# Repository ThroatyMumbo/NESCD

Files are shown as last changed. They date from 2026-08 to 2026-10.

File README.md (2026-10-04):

# NESCD-001

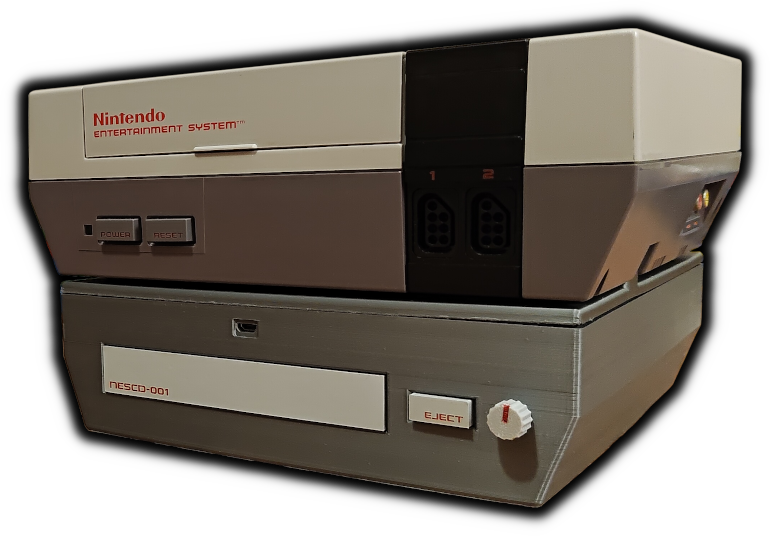
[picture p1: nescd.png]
NESCD-001


An unofficial homemade CD add-on for the NES, just because!

This repo contains the schematics, PCB, 3D printable STLs for the shell, sticker labels, and the firmware.

## How it works

It's basically an RP2350B hooked up to both an Everdrive N8 Pro and an IDE CD drive. It reads the game ROM off the CD, uploads it to the Everdrive over USB
and asks the menu to install it, then watches a mailbox byte in the cart's CHR RAM for the game to ask for music. The RP2350B is the coordinator in the
middle that bridges the NES/Everdrive and the CD drive.

Project video: https://www.youtube.com/watch?v=6D8RWVwW4ZI

## Hardware
- The main PCB (see [pcb/](pcb/))
- A standard 40-pin IDE CD drive
- Everdrive N8 Pro

## Build

```
cd firmware && ./flash.sh
```

## Making a disc

The demo game needs [cc65](https://cc65.github.io/) (`ca65`/`ld65`), plus
`python3` with `numpy`, `ffmpeg` for the audio, and `xorriso` to burn.

```
cd game && make         # demo.nes, four music tracks, and build/demo.img
cd game && make burn    # burn build/demo.img and read it back to check
```

To put your own game on a disc, pass [`mkgamedisc.py`](firmware/tools/mkgamedisc.py)
an iNES ROM and one track per music byte:

```
python3 firmware/tools/mktrack.py theme.wav -o theme.rom --loop-start 4.2
python3 firmware/tools/mkgamedisc.py -o mygame.img --title "MY GAME" --nes mygame.nes --track 1=theme.rom --verify
firmware/burn.sh mygame.img
```

## Using it

If everything goes right, you should be able to just put a burned disc into the CD drive while the NES is on and sitting on the Everdrive menu.
It'll auto-boot the game once it's read and uploaded to the Everdrive.

### Playing an audio CD

Arguably the most practical use for this thing: A CD player!

Insert the CD while on the Everdrive menu and it should automatically launch the player.

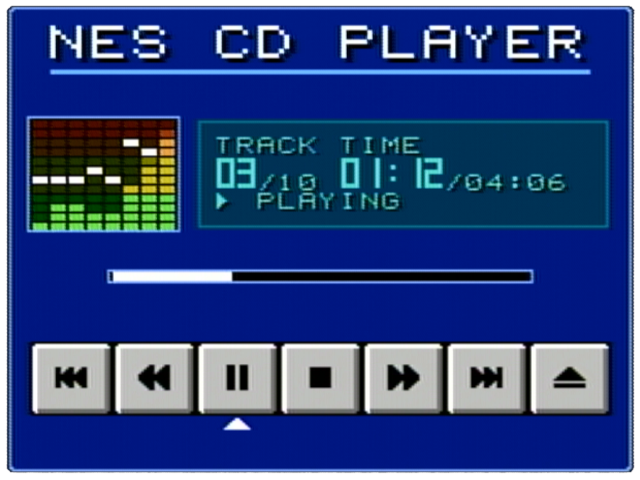
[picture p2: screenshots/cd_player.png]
Audio CD player


## FAQ

### What?
Great question! I came up with the idea for this project while reading about the canceled SNES CD-ROM add-on. I was originally going to make my own
version of that add-on, but decided it'd be funnier and weirder if I took it a step further and made one for NES.

### Why?
Because it's fun.

### Who?
It's me! Your old pal - Throaty Mumbo!

### Where are the FMVs you showed in the video?
I chose not to include any FMV-related code here because to get that working I had to semi-reverse engineer
Something Nerdy's [Bad Apple!! Ultimate NES Demake](https://somethingnerdy.com/downloads/), which is currently closed source.
The team has mentioned they're planning to formally open source their MXM mapper (which this demo presumably uses, actually not sure)
once their game *Former Dawn* is released. I didn't feel good about publishing reverse engineered code from an indie development team
for my stupid meme project, especially when they have plans to release it themselves.

### Why not stream audio from the Everdrive?
I originally wanted to do this, but was hitting a ceiling on the Everdrive USB bandwidth. I'd likely have to add some form of aggressive compression
to make room. It's also a nice touch to use the expansion port instead.

The USB cable poking out on the front is by far the biggest blemish on the design of this contraption, so I did look at moving everything to the
expansion port. Unfortunately the bandwidth there is even more limited than the USB route.

Plus, the expansion port audio allows more flexibility with mixing and volume control - hence the volume knob on the front.

### How is this thing powered?
A single molex cable from a wall adapter ([this one](https://www.amazon.com/Coolerguys-100-240v-Molex-Power-Adapter/dp/B000MGG6SC) in particular).
The 5V/12V rails are split between the CD drive and the board + the NES output. I took the end of a spare NES power cable and hooked it up to
a buck converter that converts the 12V input to ~9.5V so you can power the NES as well (the plug pokes out of the top of the box). That way
you only need one wall outlet to get the entire thing running. You can also power the NES separately from its regular adapter - the plug
coming out of the NESCD is optional.

### Couldn't you power everything off VRAW?
This was my initial plan, but it seemed tight considering the stock NES adapter (1.3A) has to power the NES, Everdrive, RP2350, DAC, and the CD drive.
The power adapter for that Fideco drive sled I tested with initially outputs at 2A, so I figured a dedicated 2A molex adapter (which supposedly outputs 2A on
5V and 12V each, at least according to the label) would be the minimum. But honestly I didn't actually test running the CD drive and everything else off
VRAW at the same time, so this was more of a cautious choice than based off of objective measurement. If it works it'd be a nice improvement for
an eventual v2 design.

### How do you get back to the Everdrive menu once you've inserted a disc?
This is still something I'm trying to figure out. AFAIK there's no way to trigger a soft reset on the NES. However one guaranteed solution is to
hook up the NES power output rail to a relay switch. That way if the board ever needs the NES to reset, it can just turn it on and off from the
source. Not super elegant but it should work.

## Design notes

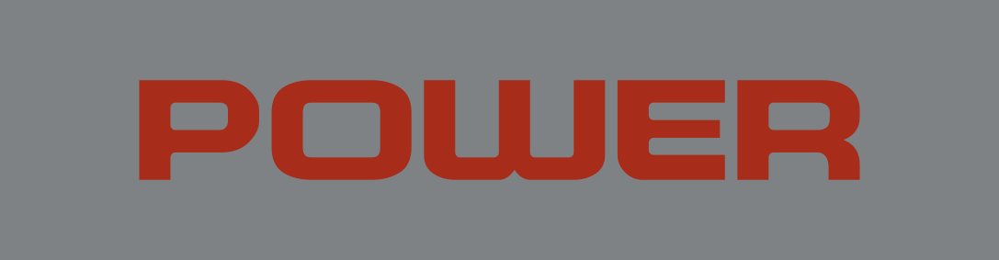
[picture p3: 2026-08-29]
labels/power_label.png

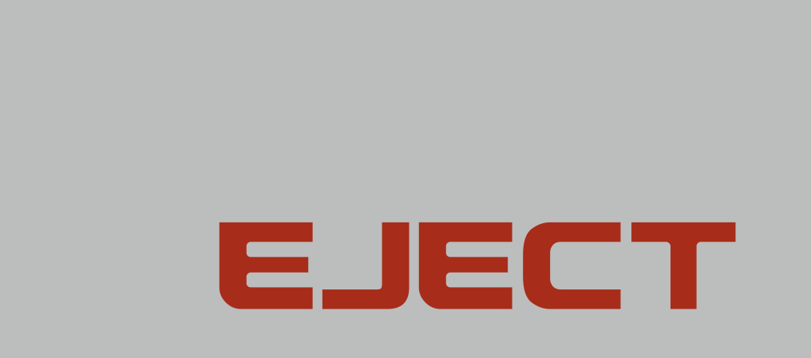
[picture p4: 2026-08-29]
labels/button_label.png

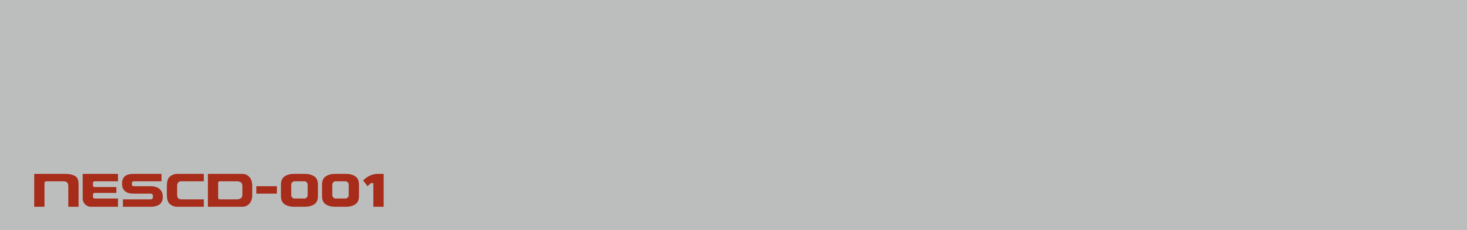
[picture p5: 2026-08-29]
labels/cd_label.png

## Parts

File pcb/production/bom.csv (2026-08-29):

Designator | Footprint | Quantity | Value | LCSC Part #
A1 | Pimoroni_PGA2350 | 1 | PGA2350
A2 | PCM5102A_Board | 1 | PCM5102A
C1 | CP_Radial_D6.3mm_P2.50mm | 1 | 100u/16V
C2, C3, C5, C6, C8 | C_Disc_D5.0mm_W2.5mm_P5.00mm | 5 | 100n
C4 | CP_Radial_D5.0mm_P2.50mm | 1 | 22u/10V
C7 | CP_Radial_D5.0mm_P2.50mm | 1 | 22u/16V
H1, H2, H3, H4 | MountingHole_3.2mm_M3_DIN965_Pad | 4 | M3
J1 | TE_MATE-N-LOK_350211-1_1x04_P5.08mm_Vertical | 1 | MOLEX IN
J2 | TE_MATE-N-LOK_350211-1_1x04_P5.08mm_Vertical | 1 | MOLEX TO DRIVE
J3 | TerminalBlock_Phoenix_MKDS-1,5-4-5.08_1x04_P5.08mm_Horizontal | 1 | PWR SWITCH
J4 | TerminalBlock_Phoenix_MKDS-1,5-2-5.08_1x02_P5.08mm_Horizontal | 1 | 12V TO BUCK
J5 | IDC-Header_2x20_P2.54mm_Vertical | 1 | IDE 40
J6 | USB_Micro_DIP_1x05_P2.54mm | 1 | USB TO EVERDRIVE
J7 | PinHeader_1x05_P2.54mm_Vertical | 1 | SWD+UART
J8 | PinHeader_1x03_P2.54mm_Vertical | 1 | PANEL POT 10k
J9 | PinHeader_2x10_P2.54mm_Vertical | 1 | SPARE GPIO
R1 | R_Axial_DIN0207_L6.3mm_D2.5mm_P7.62mm_Horizontal | 1 | 1k
TP1 | TestPoint_THTPad_D1.5mm_Drill0.7mm | 1 | +5V
TP2 | TestPoint_THTPad_D1.5mm_Drill0.7mm | 1 | +3V3
TP3 | TestPoint_THTPad_D1.5mm_Drill0.7mm | 1 | +12V
TP4 | TestPoint_THTPad_D1.5mm_Drill0.7mm | 1 | GND

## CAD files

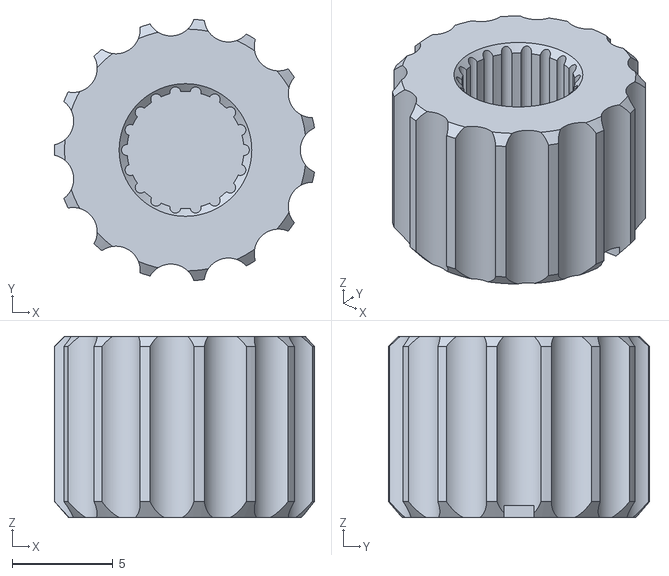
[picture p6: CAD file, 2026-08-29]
models/pot_knob.stl
12.9 x 13.0 x 9.00

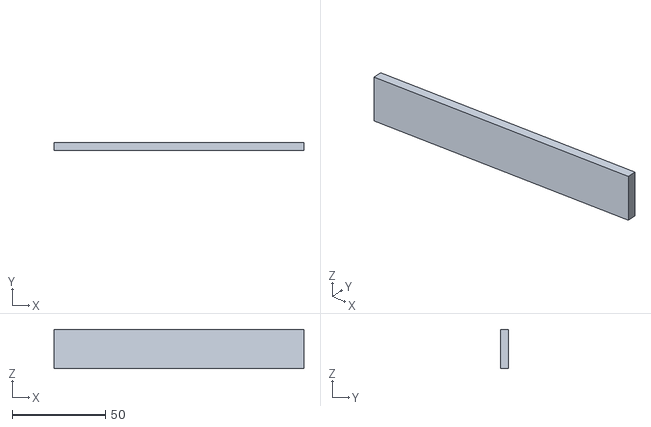
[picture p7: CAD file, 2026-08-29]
models/cd_tray_cover.stl
134.0 x 4.54 x 21.0

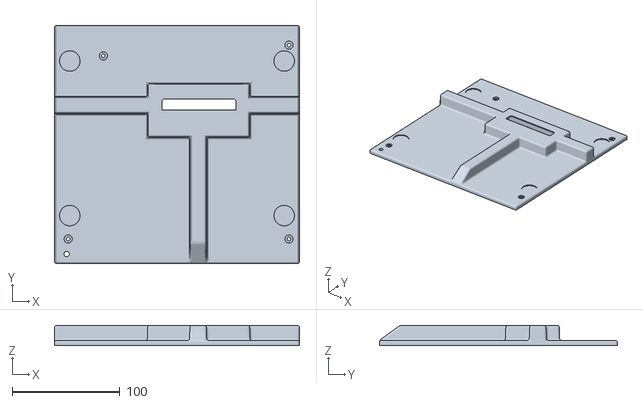
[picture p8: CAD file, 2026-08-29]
models/shell_top.stl
227.5 x 221.4 x 18.8

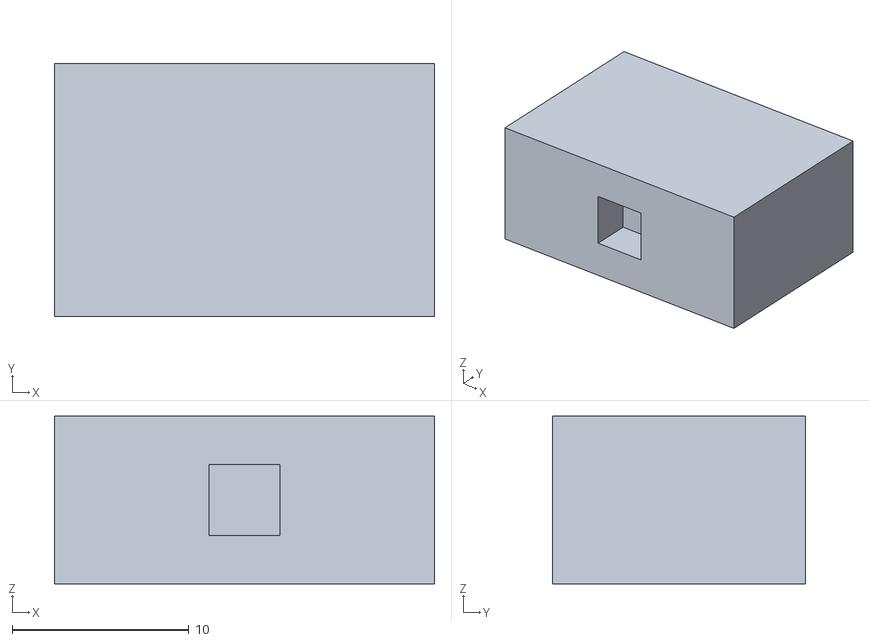
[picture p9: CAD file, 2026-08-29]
models/cd_eject_button.stl
21.5 x 14.3 x 9.50

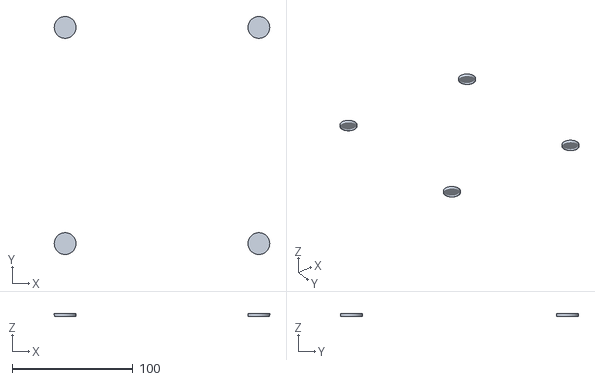
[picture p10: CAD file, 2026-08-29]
models/shell_feet.stl
178.6 x 197.2 x 2.50

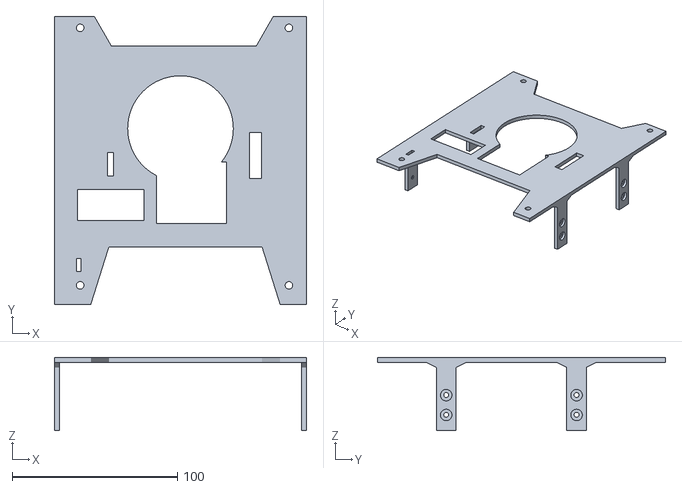
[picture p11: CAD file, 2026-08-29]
models/cd_drive_bracket.stl
152.8 x 174.5 x 44.3

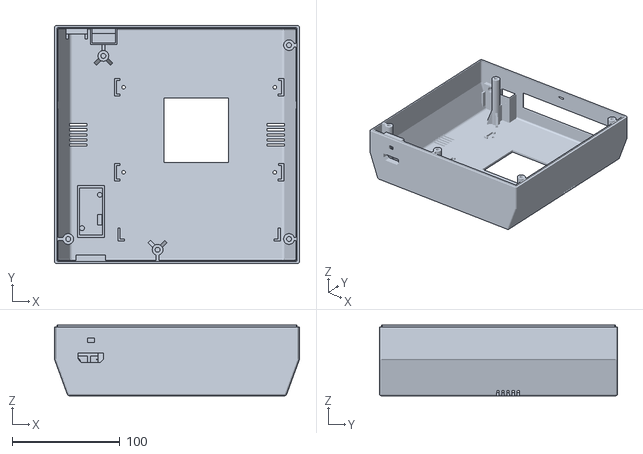
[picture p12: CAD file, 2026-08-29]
models/shell_bottom.stl
227.5 x 221.4 x 65.7

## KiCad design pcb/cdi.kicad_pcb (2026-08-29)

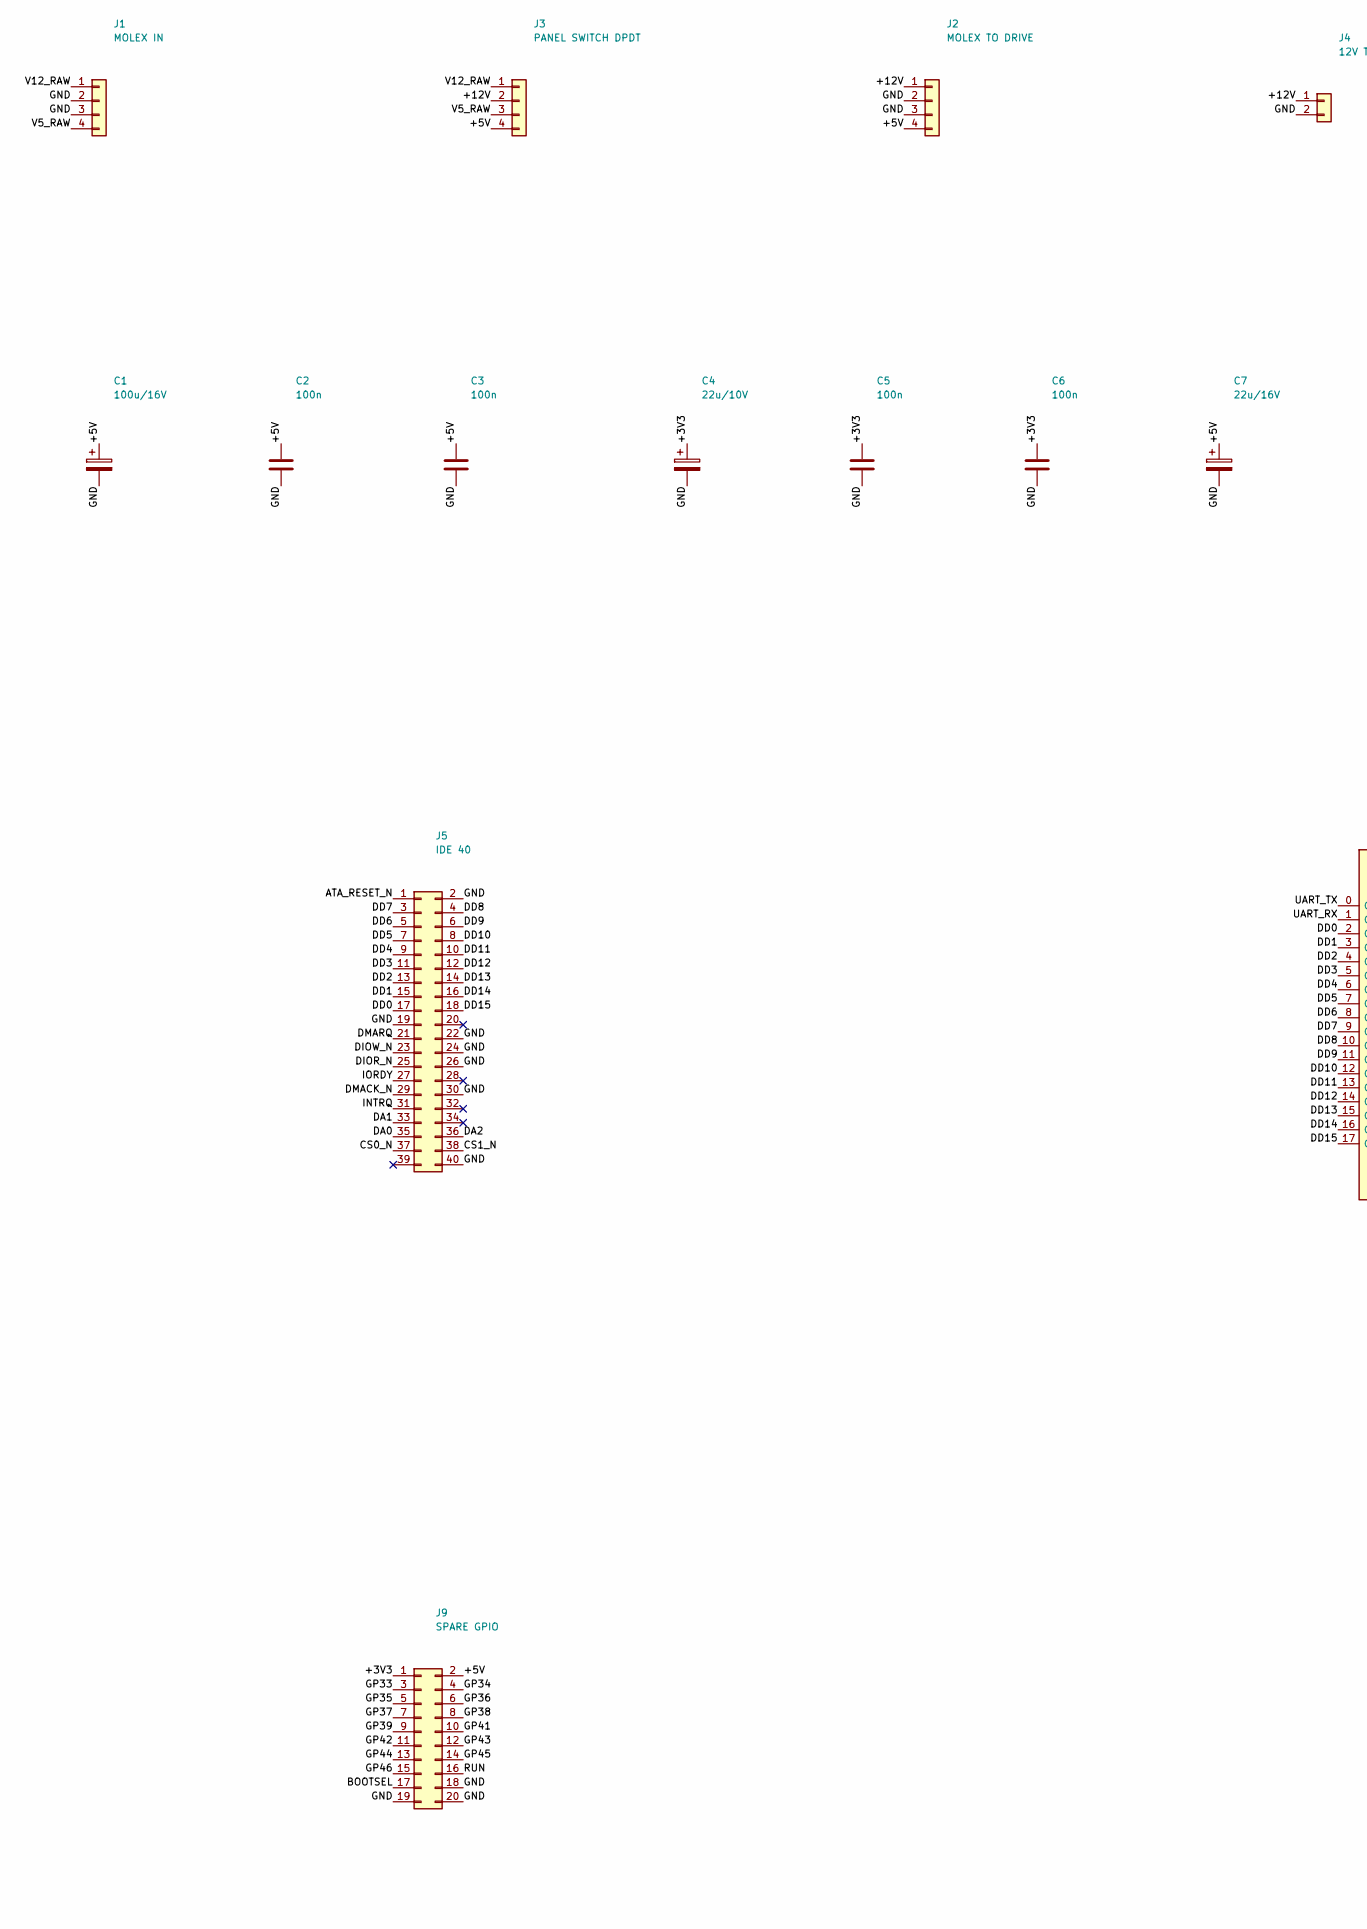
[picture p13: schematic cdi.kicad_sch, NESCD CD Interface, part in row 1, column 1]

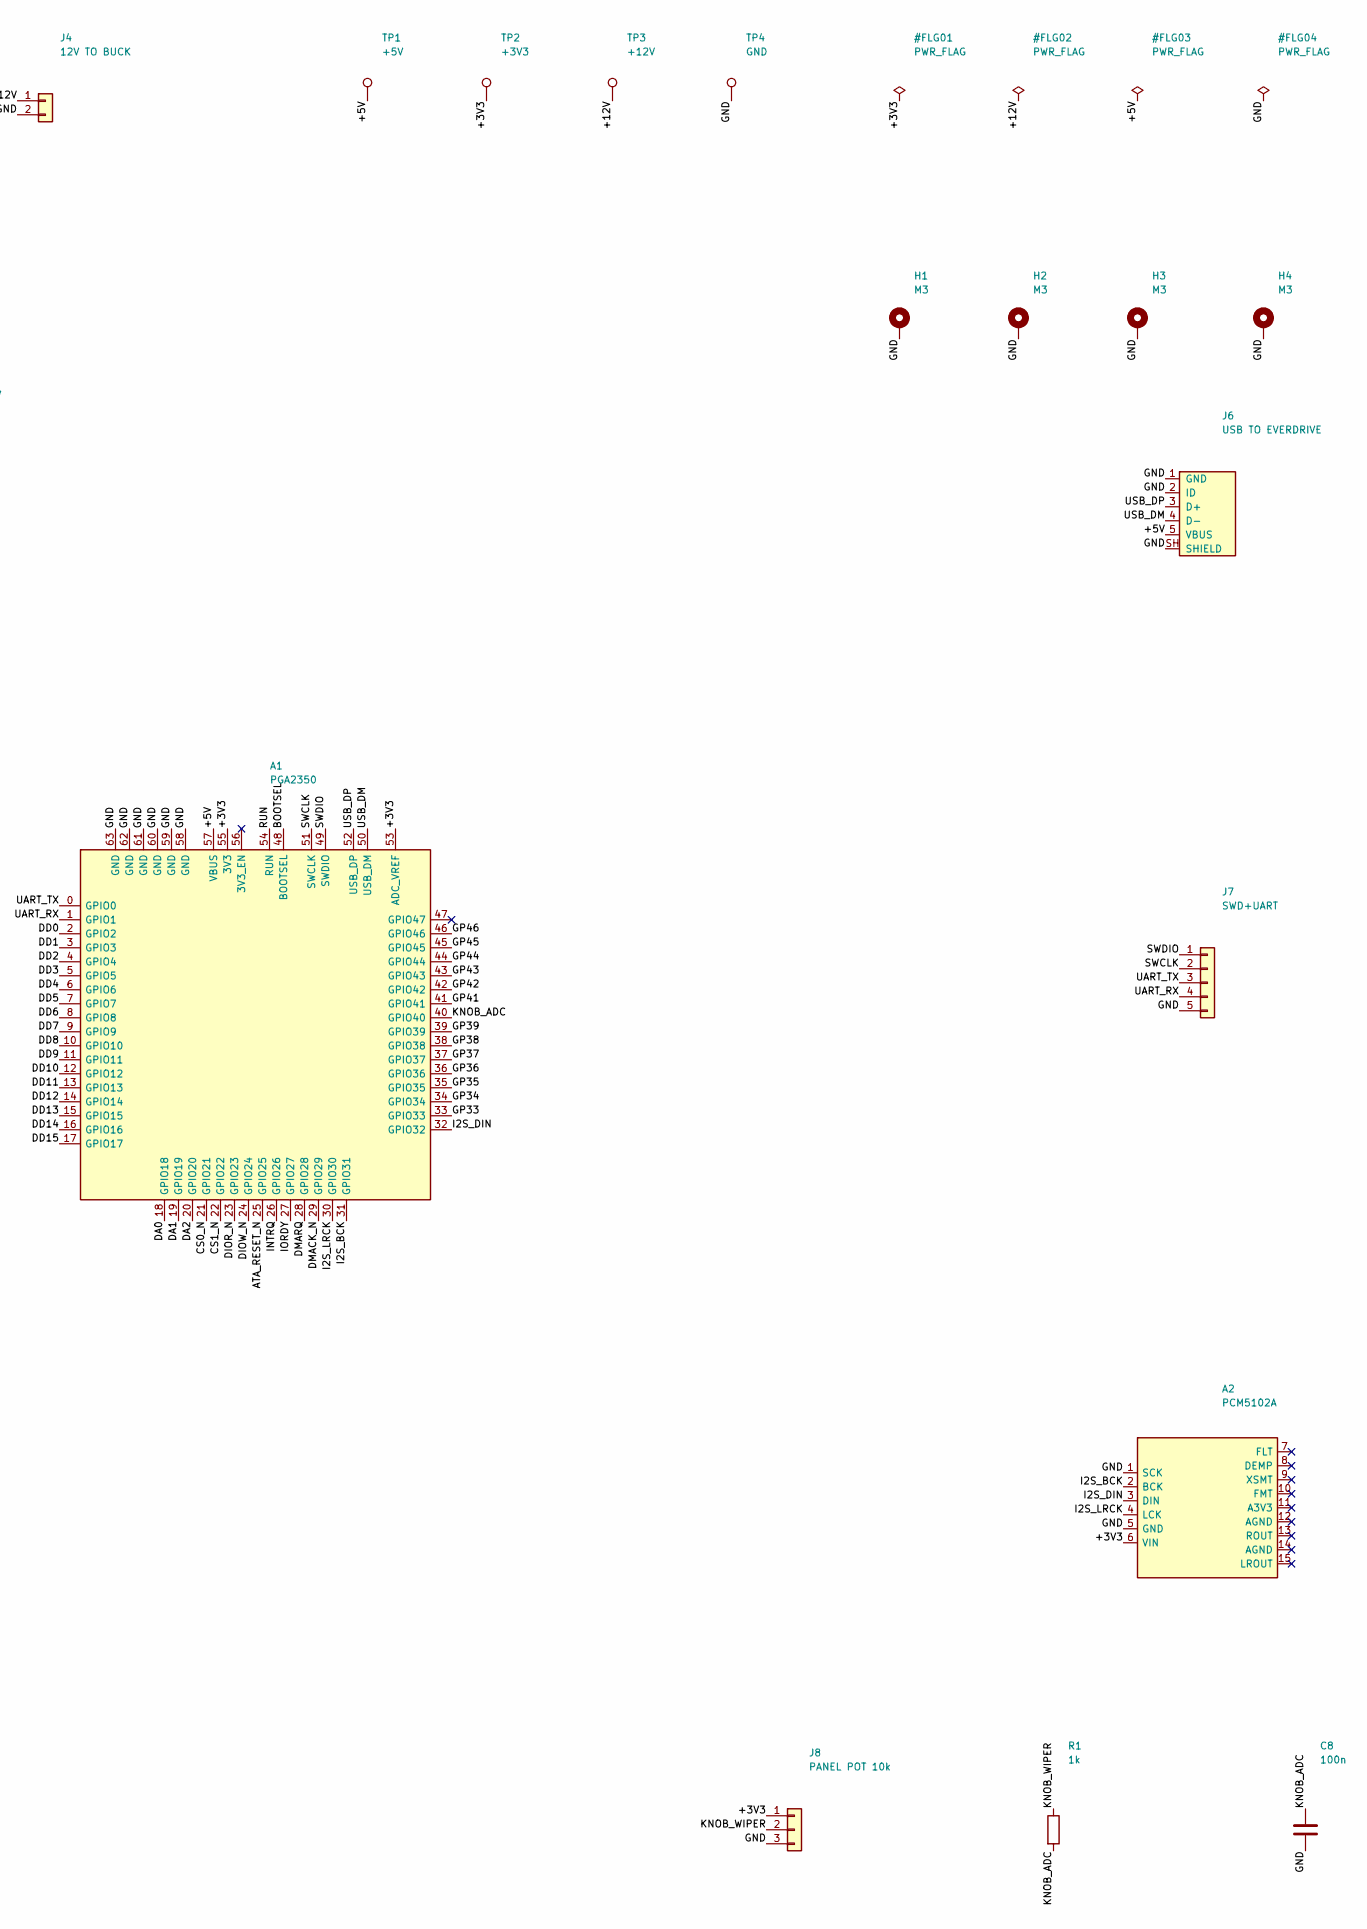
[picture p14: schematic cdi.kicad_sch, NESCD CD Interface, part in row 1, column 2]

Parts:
A1: PGA2350; Pimoroni_PGA2350
A2: PCM5102A; PCM5102A_Board
C1: 100u/16V; CP_Radial_D6.3mm_P2.50mm
C2, C3, C5, C6, C8: 100n; C_Disc_D5.0mm_W2.5mm_P5.00mm
C4: 22u/10V; CP_Radial_D5.0mm_P2.50mm
C7: 22u/16V; CP_Radial_D5.0mm_P2.50mm
H1, H2, H3, H4: M3; MountingHole_3.2mm_M3_DIN965_Pad
J1: MOLEX IN; TE_MATE-N-LOK_350211-1_1x04_P5.08mm_Vertical
J2: MOLEX TO DRIVE; TE_MATE-N-LOK_350211-1_1x04_P5.08mm_Vertical
J3: PANEL SWITCH DPDT; TerminalBlock_Phoenix_MKDS-1,5-4-5.08_1x04_P5.08mm_Horizont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
J4: 12V TO BUCK; TerminalBlock_Phoenix_MKDS-1,5-2-5.08_1x02_P5.08mm_Horizont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
J5: IDE 40; IDC-Header_2x20_P2.54mm_Vertical
J6: USB TO EVERDRIVE; USB_Micro_DIP_1x05_P2.54mm
J7: SWD+UART; PinHeader_1x05_P2.54mm_Vertical
J8: PANEL POT 10k; PinHeader_1x03_P2.54mm_Vertical
J9: SPARE GPIO; PinHeader_2x10_P2.54mm_Vertical
R1: 1k; R_Axial_DIN0207_L6.3mm_D2.5mm_P7.62mm_Horizontal
TP1: +5V; TestPoint_THTPad_D1.5mm_Drill0.7mm
TP2: +3V3; TestPoint_THTPad_D1.5mm_Drill0.7mm
TP3: +12V; TestPoint_THTPad_D1.5mm_Drill0.7mm
TP4: GND; TestPoint_THTPad_D1.5mm_Drill0.7mm

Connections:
/+3V3: A1.53 (ADC_VREF), A1.55 (3V3), A2.6 (VIN), C4.1, C5.1, C6.1, J8.1, J9.1, TP2.1 (1_1)
/+5V: A1.57 (VBUS), C1.1, C2.1, C3.1, C7.1, J2.4, J3.4, J6.5 (VBUS), J9.2, TP1.1 (1_1)
/+12V: J2.1, J3.2, J4.1, TP3.1 (1_1)
/ATA_RESET_N: A1.25 (GPIO25), J5.1
/BOOTSEL: A1.48 (BOOTSEL), J9.17
/CS0_N: A1.21 (GPIO21), J5.37
/CS1_N: A1.22 (GPIO22), J5.38
/DA0: A1.18 (GPIO18), J5.35
/DA1: A1.19 (GPIO19), J5.33
/DA2: A1.20 (GPIO20), J5.36
/DD0: A1.2 (GPIO2), J5.17
/DD1: A1.3 (GPIO3), J5.15
/DD2: A1.4 (GPIO4), J5.13
/DD3: A1.5 (GPIO5), J5.11
/DD4: A1.6 (GPIO6), J5.9
/DD5: A1.7 (GPIO7), J5.7
/DD6: A1.8 (GPIO8), J5.5
/DD7: A1.9 (GPIO9), J5.3
/DD8: A1.10 (GPIO10), J5.4
/DD9: A1.11 (GPIO11), J5.6
/DD10: A1.12 (GPIO12), J5.8
/DD11: A1.13 (GPIO13), J5.10
/DD12: A1.14 (GPIO14), J5.12
/DD13: A1.15 (GPIO15), J5.14
/DD14: A1.16 (GPIO16), J5.16
/DD15: A1.17 (GPIO17), J5.18
/DIOR_N: A1.23 (GPIO23), J5.25
/DIOW_N: A1.24 (GPIO24), J5.23
/DMACK_N: A1.29 (GPIO29), J5.29
/DMARQ: A1.28 (GPIO28), J5.21
/GND: A1.58 (GND), A1.59 (GND), A1.60 (GND), A1.61 (GND), A1.62 (GND), A1.63 (GND), A2.1 (SCK), A2.5 (GND), C1.2, C2.2, C3.2, C4.2, C5.2, C6.2, C7.2, C8.2, H1.1 (1_1), H2.1 (1_1), H3.1 (1_1), H4.1 (1_1), J1.2, J1.3, J2.2, J2.3, J4.2, J5.2, J5.19, J5.22, J5.24, J5.26, J5.30, J5.40, J6.1 (GND), J6.2 (ID), J6.SH (SHIELD), J7.5, J8.3, J9.18, J9.19, J9.20, TP4.1 (1_1)
/GP33: A1.33 (GPIO33), J9.3
/GP34: A1.34 (GPIO34), J9.4
/GP35: A1.35 (GPIO35), J9.5
/GP36: A1.36 (GPIO36), J9.6
/GP37: A1.37 (GPIO37), J9.7
/GP38: A1.38 (GPIO38), J9.8
/GP39: A1.39 (GPIO39), J9.9
/GP41: A1.41 (GPIO41), J9.10
/GP42: A1.42 (GPIO42), J9.11
/GP43: A1.43 (GPIO43), J9.12
/GP44: A1.44 (GPIO44), J9.13
/GP45: A1.45 (GPIO45), J9.14
/GP46: A1.46 (GPIO46), J9.15
/I2S_BCK: A1.31 (GPIO31), A2.2 (BCK)
/I2S_DIN: A1.32 (GPIO32), A2.3 (DIN)
/I2S_LRCK: A1.30 (GPIO30), A2.4 (LCK)
/INTRQ: A1.26 (GPIO26), J5.31
/IORDY: A1.27 (GPIO27), J5.27
/KNOB_ADC: A1.40 (GPIO40), C8.1, R1.2
/KNOB_WIPER: J8.2, R1.1
/RUN: A1.54 (RUN), J9.16
/SWCLK: A1.51 (SWCLK), J7.2
/SWDIO: A1.49 (SWDIO), J7.1
/UART_RX: A1.1 (GPIO1), J7.4
/UART_TX: A1.0 (GPIO0), J7.3
/USB_DM: A1.50 (USB_DM), J6.4 (D-)
/USB_DP: A1.52 (USB_DP), J6.3 (D+)
/V5_RAW: J1.4, J3.3
/V12_RAW: J1.1, J3.1

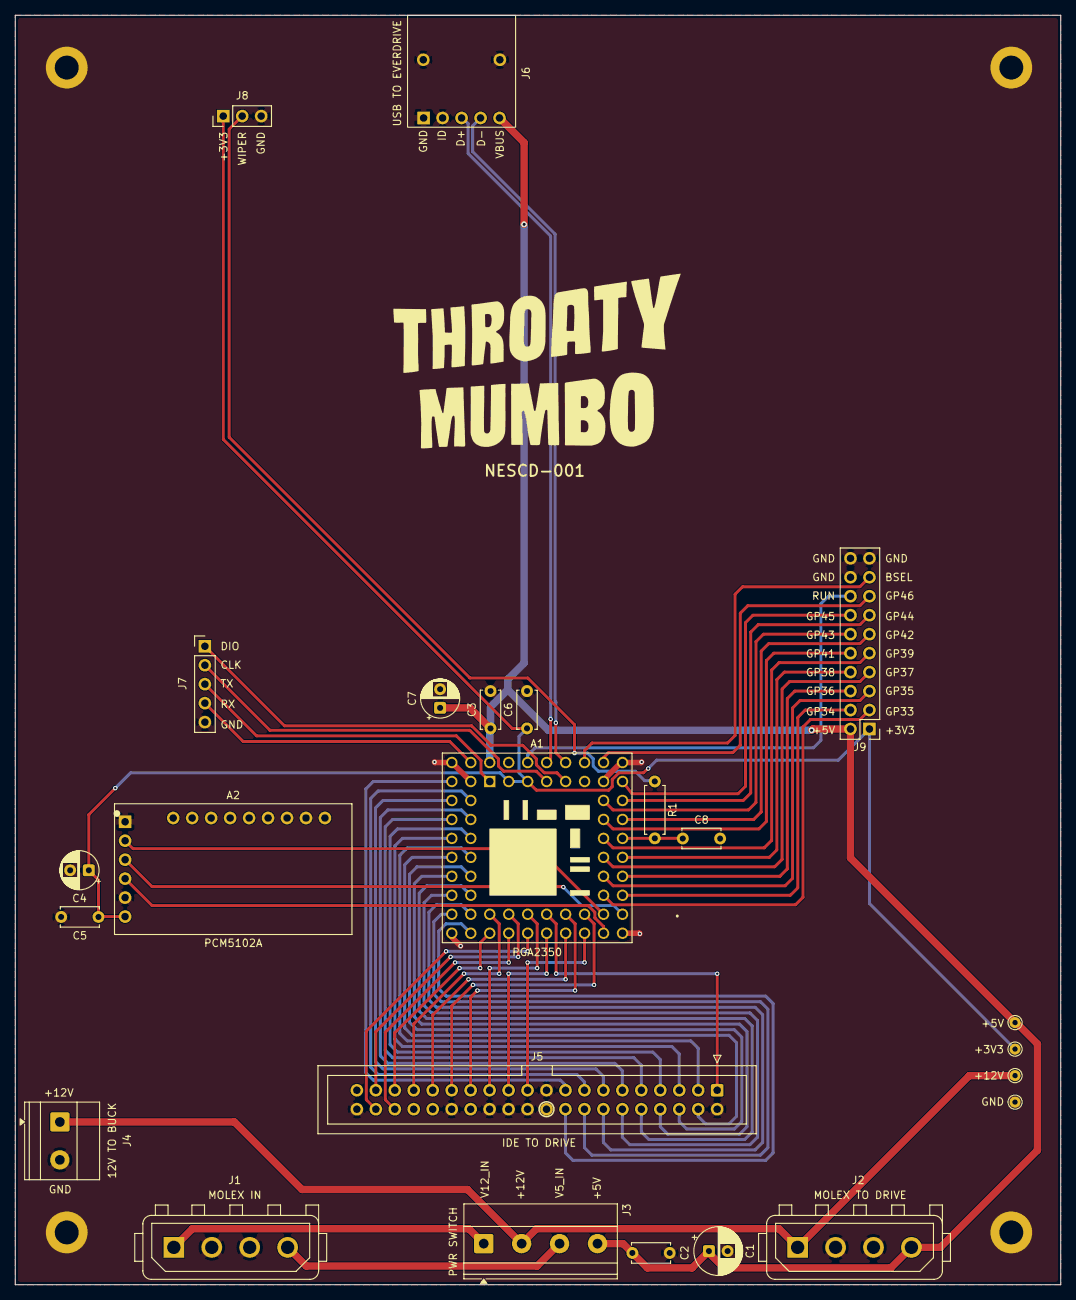
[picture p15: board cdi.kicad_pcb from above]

Board: 2 copper layers, 140.0 x 170.0 mm, 28 parts (0 on the bottom side), 60 nets.

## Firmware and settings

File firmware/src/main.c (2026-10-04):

#include <stdio.h>
#include <string.h>
#include <stdlib.h>
#include "pico/stdlib.h"
#include "hardware/clocks.h"
#include "hardware/regs/usb.h"
#include "hardware/xip_cache.h"
#include "ata.h"
#include "atapi.h"
#include "audio.h"
#include "bgm.h"
#include "catalog.h"
#include "cdcore.h"
#include "cdda.h"
#include "diag.h"
#include "disc.h"
#include "disctask.h"
#include "edn8.h"
#include "eject.h"
#include "jingle.h"
#include "tone.h"
#include "knob.h"
#include "mailbox.h"
#include "n8push.h"
#include "player.h"
#include "psram.h"
#include "track.h"
#include "usb_link.h"

#define SECTOR_BYTES  2048u
#define BULK_SECTORS  16u                     // sectors per READ(10) in 'b'
#define RUN_LED_PIN   42u                     // panel red LED: steady = cart linked, 2 Hz blink = no cart
#define RUN_LED_MS    250u

static repeating_timer_t run_led_timer;

static bool __not_in_flash_func(run_led_tick)(repeating_timer_t *t)
{
    (void)t;
    gpio_put(RUN_LED_PIN, usb_link_state()->mounted || !gpio_get_out_level(RUN_LED_PIN));
    return true;
}

static uint16_t identify[256]                       __attribute__((aligned(4)));
static uint8_t  sector[SECTOR_BYTES]                __attribute__((aligned(4)));
static uint8_t  bulk[BULK_SECTORS * SECTOR_BYTES]   __attribute__((aligned(4)));

static bool autoplay_on = true;      // boot a disc as it is inserted

static void hexdump(const uint8_t *p, int n)
{
    for (int i = 0; i < n; i += 16) {
        printf("%04x: ", i);
        for (int j = 0; j < 16 && i + j < n; j++) printf("%02x ", p[i + j]);
        printf(" |");
        for (int j = 0; j < 16 && i + j < n; j++) {
            uint8_t c = p[i + j];
            putchar((c >= 0x20 && c < 0x7f) ? c : '.');
        }
        printf("|\n");
    }
}

static void help(void)
{
    printf("\nnescd - ATAPI host on PGA2350\n"
           "  h            help\n"
           "  x            hard reset + IDENTIFY\n"
           "  i            IDENTIFY PACKET DEVICE\n"
           "  q            INQUIRY\n"
           "  u            TEST UNIT READY (waits for spin-up)\n"
           "  e | l        eject / load tray\n"
           "  k <n>        SET CD SPEED to n x (0 = max)\n"
           "  c            READ CAPACITY\n"
           "  d <lba>      READ(10) one sector + hexdump\n"
           "  b <lba> <n>  timed bulk read of n sectors\n"
           "  r <hex...>   raw CDB (up to 12 bytes)\n"
           "  t <0..2>     ATA PIO timing mode (now %u, %lu ns cycle)\n"
           "  A <lba>      async sector read, counts USB pumps during it\n"
           "  R            force the bus idle, restart the PIO machines\n"
           "everdrive n8 pro over usb host:\n"
           "  n            USB link state / enumerated device\n"
           "  a            open the link: wake, identify, sys info\n"
           "  o <addr> <n> mem_rd + hexdump (addr accepts 0x...)\n"
           "  v [bytes]    PSRAM round-trip memtest (default 4096)\n"
           "  y [bytes]    mem_wr/mem_rd throughput bench (default 256K)\n"
           "  E            staged cart payload: manifest + crc (E, not e)\n"
           "  W            write it to the cart's SD and boot it (needs the menu)\n"
           "game disc (rom + music tracks, autoplay boots it):\n"
           "  L [v]        the catalog; L v also reads every item's crc\n"
           "  J [s|x|d]    stage the ROM item, push it to the cart and boot (s: stage\n"
           "               only; x: cart-ROM mode, the ROM on the cart is the game and\n"
           "               the disc's is never pushed; d: back to disc mode)\n"
           "  G [0|1]      arm the game's music mailbox against the open disc\n"
           "  S            track reader statistics and buffer depth\n"
           "  O [0|1]      autoplay on insertion, and the disc's ROM or the CD player\n"
           "               on the menu (now %s)\n"
           "  Y            spin the drive up after a failed acquisition\n"
           "  (the panel button on GP33 toggles the tray, between commands)\n"
           "audio cd player (the NCDP ROM on the cart drives it through the mailbox):\n"
           "  C            state, track, the drive's cd-da capability\n"
           "  C t          the disc's table of contents\n"
           "  C p [n]      play track n (or resume); C h pause/resume; C s stop\n"
           "  C n | v      next / previous track;  C e | l  eject / load\n"
           "  G p          arm the player by hand (it arms itself on the ROM)\n"
           "audio out (pcm5102 i2s dac):\n"
           "  M            toggle the jingle\n"
           "  B [track]    play track n off the disc as background music, its loop\n"
           "               range honored; bare B stops (the game's mailbox\n"
           "               overrides while G is armed)\n"
           "  V [-dB|k]    output level, 0 to -%d dBFS, lower mutes (now %d); V k = pot\n"
           "  T [hz] [l|r] toggle a full-scale sine for level calibration\n"
           "on-board psram:\n"
           "  P [bytes]    size, memtest, throughput, cache checks (default 1M)\n"
           "wiring diagnostics (no live drive needed):\n"
           "  g            snapshot every line: GPIO, ATA pin, level\n"
           "  f            float scan - which lines nothing is driving\n"
           "  w            short scan - which lines are tied together\n"
           "  p <gpio>     toggle one GPIO at 2Hz for 10s, to trace it\n"
           "  m            live monitor, print on any change\n\n",
           ata_get_pio_mode(), (unsigned long)ata_get_cycle_ns(),
           autoplay_on ? "on" : "off", AUDIO_ATTEN_MAX, audio_get_atten_db());
}

static void show_status(void)
{
    uint8_t s = ata_altstatus();
    printf("  status %02x [%s%s%s%s%s]\n", s,
           (s & ATA_ST_BSY)  ? "BSY "  : "",
           (s & ATA_ST_DRDY) ? "DRDY " : "",
           (s & ATA_ST_DSC)  ? "DSC "  : "",
           (s & ATA_ST_DRQ)  ? "DRQ "  : "",
           (s & ATA_ST_ERR)  ? "ERR "  : "");
}

static void report(const char *what, int rc)
{
    if (rc == ATAPI_OK) { printf("  %s: ok\n", what); return; }
    printf("  %s: %s", what, atapi_strerror(rc));
    if (rc == ATAPI_ECHECK)
        printf(" - sense %x/%02x/%02x (%s)", atapi_sense_key, atapi_sense_asc,
               atapi_sense_ascq, atapi_sense_text(atapi_sense_key));
    printf("\n");
}

// A drive can hold itself unready for many seconds after a reset; the standard
// allows up to 31. Report the ATAPI signature once it settles.
static void do_reset_wait(void)
{
    uint8_t mid = 0, high = 0;
    if (!ata_wait_signature(31000)) {
        ata_read_signature(&mid, &high);
        printf("  no ATAPI signature after 31s (got %02x/%02x, status %02x)\n",
               mid, high, ata_altstatus());
        return;
    }
    ata_read_signature(&mid, &high);
    printf("  ready, signature %02x/%02x (ATAPI), status %02x\n",
           mid, high, ata_altstatus());
}

static void do_identify(void)
{
    if (!ata_identify_packet(identify)) {
        printf("  IDENTIFY PACKET DEVICE failed\n");
        show_status();
        return;
    }
    char s[64];
    ata_id_string(identify, 27, 20, s, sizeof(s)); printf("  model:    %s\n", s);
    ata_id_string(identify, 23,  4, s, sizeof(s)); printf("  firmware: %s\n", s);
    ata_id_string(identify, 10, 10, s, sizeof(s)); printf("  serial:   %s\n", s);
    printf("  config:   %04x %s\n", identify[0],
           ((identify[0] >> 14) == 2) ? "(ATAPI packet device)" : "(not ATAPI?)");
    printf("  pio:      up to mode %u, iordy %s",
           (unsigned)(identify[51] >> 8),
           (identify[49] & (1u << 11)) ? "yes" : "no");
    if (identify[53] & 2u) printf(", advanced modes %02x", identify[64] & 3u);
    printf("\n");
}

// Word 51's high byte is the highest PIO mode the drive claims. Modes 3 and 4
// live in word 64 and need IORDY, which this host does not honor.
static void do_timing(const char *arg)
{
    if (*arg) {
        uint m = (uint)strtoul(arg, NULL, 10);
        if (m > ATA_PIO_MODE_MAX) {
            printf("  mode %u needs IORDY flow control; 0..%u only\n",
                   m, ATA_PIO_MODE_MAX);
            return;
        }
        uint claimed = identify[51] >> 8;
        if (identify[0] && m > claimed)
            printf("  warning: drive claims only PIO mode %u\n", claimed);
        if (m > 0)
            printf("  warning: mode %u entitles the drive to assert IORDY,\n"
                   "           which this host ignores - re-check d <lba>\n", m);
        if (!ata_set_xfer_mode(m))
            printf("  warning: SET FEATURES rejected, host retimed anyway\n");
        ata_set_pio_mode(m);
    }
    ata_timing_report();
}

// Proof that the bus no longer owns the CPU: count how many times the USB
// host stack gets pumped while a sector is in flight.
static void do_async(uint32_t lba)
{
    uint8_t cdb[ATAPI_CDB_LEN] = {
        ATAPI_READ10, 0,
        (uint8_t)(lba >> 24), (uint8_t)(lba >> 16), (uint8_t)(lba >> 8), (uint8_t)lba,
        0, 0, 1, 0, 0, 0
    };

    if (!ata_wait_not_bsy(5000)) { printf("  drive busy\n"); return; }
    ata_select_device(0);
    ata_reg_write8(ATA_CS_CMD, ATA_REG_FEATURES,  0);
    ata_reg_write8(ATA_CS_CMD, ATA_REG_BCOUNT_LO, SECTOR_BYTES & 0xFFu);
    ata_reg_write8(ATA_CS_CMD, ATA_REG_BCOUNT_HI, (SECTOR_BYTES >> 8) & 0xFFu);
    ata_reg_write8(ATA_CS_CMD, ATA_REG_COMMAND,   ATA_CMD_PACKET);
    if (!ata_wait_drq(5000)) { printf("  no DRQ for the CDB\n"); return; }

    uint16_t words[ATAPI_CDB_LEN / 2];
    memcpy(words, cdb, ATAPI_CDB_LEN);
    ata_write_data_burst(words, ATAPI_CDB_LEN / 2);

    if (!ata_wait_drq(30000)) { printf("  no data DRQ\n"); return; }
    if (!ata_read_begin((uint16_t *)sector, SECTOR_BYTES / 2)) {
        printf("  async path declined (alignment or a read in flight)\n");
        return;
    }

    uint32_t pumps = 0;
    while (!ata_read_poll()) { usb_link_pump(); pumps++; }
    ata_read_end();

    ata_wait_not_bsy(5000);
    printf("  LBA %lu read, %lu USB pump(s) during the transfer\n",
           (unsigned long)lba, (unsigned long)pumps);
    hexdump(sector, 64);
}

static void do_capacity(void)
{
    uint32_t last = 0, bsz = 0;
    int rc = atapi_read_capacity(&last, &bsz);
    if (rc != ATAPI_OK) { report("READ CAPACITY", rc); return; }
    printf("  last LBA %lu, block %lu bytes, %lu MiB\n",
           (unsigned long)last, (unsigned long)bsz,
           (unsigned long)(((uint64_t)(last + 1) * bsz) >> 20));
}

static void do_bulk(uint32_t lba, uint32_t nsectors)
{
    if (nsectors == 0) { printf("  usage: b <lba> <sectors>\n"); return; }

    ata_stat_words = 0;
    ata_stat_bus_us = 0;
    absolute_time_t t0 = get_absolute_time();
    uint32_t done = 0;
    while (done < nsectors) {
        uint32_t chunk = nsectors - done;
        if (chunk > BULK_SECTORS) chunk = BULK_SECTORS;
        size_t got = 0;
        int rc = atapi_read10(lba + done, (uint16_t)chunk, bulk,
                              chunk * SECTOR_BYTES, &got);
        if (rc != ATAPI_OK) {
            printf("  stopped at LBA %lu after %lu sectors\n",
                   (unsigned long)(lba + done), (unsigned long)done);
            report("READ(10)", rc);
            return;
        }
        done += chunk;
    }
    int64_t us = absolute_time_diff_us(t0, get_absolute_time());
    if (us <= 0) us = 1;

    uint64_t bytes = (uint64_t)done * SECTOR_BYTES;
    printf("  %lu sectors (%lu KiB) in %lu ms = %lu KB/s wall\n",
           (unsigned long)done, (unsigned long)(bytes >> 10),
           (unsigned long)(us / 1000), (unsigned long)(bytes * 1000 / (uint64_t)us));

    // Splitting bus time out of wall time says whether the next win belongs in
    // the bus driver, in per-DRQ overhead, or in read-ahead.
    uint64_t bus_us = ata_stat_bus_us ? ata_stat_bus_us : 1;
    printf("    bus %lu words in %lu ms = %lu KB/s, %lu%% bus-bound\n",
           (unsigned long)ata_stat_words, (unsigned long)(bus_us / 1000),
           (unsigned long)(ata_stat_words * 2 * 1000 / bus_us),
           (unsigned long)(bus_us * 100 / (uint64_t)us));
}

static void do_raw(const char *arg)
{
    uint8_t cdb[ATAPI_CDB_LEN];
    char tmp[96];
    int n = 0;

    memset(cdb, 0, sizeof(cdb));
    strncpy(tmp, arg, sizeof(tmp) - 1); tmp[sizeof(tmp) - 1] = 0;
    for (char *tok = strtok(tmp, " "); tok && n < ATAPI_CDB_LEN; tok = strtok(NULL, " "))
        cdb[n++] = (uint8_t)strtoul(tok, NULL, 16);
    if (n == 0) { printf("  usage: r <hex bytes>\n"); return; }

    size_t got = 0;
    int rc = atapi_packet(cdb, sector, sizeof(sector), &got);
    printf("  CDB %02x, %u byte(s) back\n", cdb[0], (unsigned)got);
    if (got) hexdump(sector, (int)(got > 64 ? 64 : got));
    if (rc != ATAPI_OK) report("packet", rc);
}

// -- cart link -------------------------------------------------------------

static void n8_report(const char *what, int rc)
{
    if (rc == EDN8_OK) { printf("  %s: ok\n", what); return; }
    printf("  %s: %s", what, edn8_strerror(rc));
    if (rc == EDN8_ESTATUS)  printf(" - status 0x%02X", edn8_last_status);
    if (rc == EDN8_ETIMEOUT) printf(" - moved %u byte(s)", (unsigned)edn8_last_short);
    if (rc == EDN8_EWEDGED)  printf(" - %lu byte(s) owed, POWER-CYCLE the cart",
                                    (unsigned long)edn8_bytes_owed);
    printf("\n");
}

static const char *speed_name(uint8_t s)
{
    switch (s) {
    case 0:  return "full";      // tusb_speed_t: 0 full, 1 low, 2 high
    case 1:  return "low";
    case 2:  return "high";
    default: return "?";
    }
}
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
int main(void)
{
    stdio_init_all();          // UART0 console on GP0(TX)/GP1(RX)
    gpio_init(RUN_LED_PIN);
    gpio_set_dir(RUN_LED_PIN, GPIO_OUT);
    gpio_put(RUN_LED_PIN, 1);
    add_repeating_timer_ms(RUN_LED_MS, run_led_tick, NULL, &run_led_timer);

    // Before anything else touches the QMI: the M1 timing is derived from
    // clk_sys, and lines cached under the old CS1 setup are stale.
    psram_init(PSRAM_CS_PIN);
    xip_cache_invalidate_all();

    if (!ata_bus_init()) printf("ata: no PIO resources - the bus is inert\n");
    // After the ATA bus: that program wants the PIO at GPIOBASE 0, audio wants
    // one at 16, and whichever claims first fixes the base of the instance.
    bool audio_ok = audio_init();
    knob_init();
    knob_enable(true);
    audio_set_tick_hook(knob_poll);
    eject_init();
    sleep_ms(500);             // settle
    help();
    if (psram_bytes) printf("psram: %u MiB @ %08X\n",
                           (unsigned)(psram_bytes >> 20), PSRAM_XIP_BASE);
    else            printf("psram: not detected on CS1 - P is inert\n");

    // A warm reset keeps the booted ROM's identity; chip_reset cannot tell one
    // from a power-on (openocd's reset leaves it at HAD_POR).
    bool warm = boot_keep.magic == BOOT_WARM_MAGIC;
    boot_keep.magic = BOOT_WARM_MAGIC;
    if (warm) booted_crc = boot_keep.crc; else boot_keep.crc = 0;
    printf("reset: %s%s\n", warm ? "warm" : "power-on",
           booted_crc ? ", the disc's ROM is still on the cart" : "");
    if (!audio_ok) printf("audio: no PIO/DMA resources - M is inert\n");

    printf("resetting bus...\n");
    ata_hard_reset();
    do_reset_wait();           // the signature, not !BSY: a floating bus reads
    do_identify();             // 0x7f, which has BSY clear and DRQ set

    // After the ATA bring-up: ata_wait_not_bsy() blocks for up to 31s with
    // nothing pumping the host stack.
    usb_link_init();
    ata_wait_hook = usb_link_pump;   // ATA waits no longer starve the host stack
    if (disctask_init()) printf("core1: cd reader parked, %u MiB of slots\n",
                                (unsigned)(DISC_SLOTS_BYTES >> 20));
    else printf("core1: not started - no psram, tracks are unavailable\n");
    autoplay_due = make_timeout_time_ms(AUTOPLAY_BOOT_MS);

    printf("usb host: waiting for the cart...\n");
    if (usb_link_wait_ready(2000)) {
        const usb_link_state_t *s = usb_link_state();
        printf("  cdc mounted: %04X:%04X \"%s\" (idx %u)\n",
               s->vid, s->pid, s->product, s->cdc_idx);
    } else {
        printf("  no device after 2s - press n for detail\n");
    }

    char line[96];
    for (;;) {
        printf("cd> ");
        read_line(line, sizeof(line));
        if (line[0] == 0) continue;

        char cmd = line[0];
        const char *arg = &line[1];
        while (*arg == ' ') arg++;

        // Every command that touches the drive, while a track has it.
        if (strchr("xiquelkcdbrtARYLJ", cmd) && !bus_free()) continue;

        switch (cmd) {
        case 'h': help(); break;

        case 'x':
            printf("hard reset...\n");
            disc_speed_reset();
            ata_hard_reset();
            do_reset_wait();
            do_identify();
            break;

        case 'i': do_identify(); break;

        case 'q': {
            size_t got = 0;
            int rc = atapi_inquiry(sector, 36, &got);
            if (rc != ATAPI_OK) { report("INQUIRY", rc); break; }
            char s[32];
            memcpy(s, sector + 8, 8);  s[8]  = 0; printf("  vendor:  %s\n", s);
            memcpy(s, sector + 16, 16); s[16] = 0; printf("  product: %s\n", s);
            memcpy(s, sector + 32, 4);  s[4]  = 0; printf("  rev:     %s\n", s);
            printf("  type:    %02x %s\n", sector[0] & 0x1F,
                   ((sector[0] & 0x1F) == 0x05) ? "(CD-ROM)" : "");
            break;
        }

        case 'u': report("TEST UNIT READY", atapi_wait_ready(30000)); break;
        case 'e':
            disc_speed_reset();
            report("eject", atapi_start_stop(ATAPI_SS_EJECT));
            break;
        case 'l': report("load",  atapi_start_stop(ATAPI_SS_LOAD));  break;

        case 'k': {
            uint32_t x = (uint32_t)strtoul(arg, NULL, 10);
            uint16_t kb = x ? (uint16_t)(x * ATAPI_SPEED_1X) : 0xFFFFu;
            printf("set speed %lux (%u KB/s)\n", (unsigned long)x, kb);
            report("SET CD SPEED", atapi_set_cd_speed(kb));
            break;
        }

        case 'c': do_capacity(); break;

        case 'd': {
            uint32_t lba = (uint32_t)strtoul(arg, NULL, 10);
            size_t got = 0;
            printf("read LBA %lu ...\n", (unsigned long)lba);
            int rc = atapi_read10(lba, 1, sector, sizeof(sector), &got);
            if (rc != ATAPI_OK) { report("READ(10)", rc); break; }
            printf("  got %u bytes\n", (unsigned)got);
            hexdump(sector, (int)(got > 64 ? 64 : got));
            break;
        }

        case 'b': {
            char *end = NULL;
            uint32_t lba = (uint32_t)strtoul(arg, &end, 10);
            uint32_t n   = (uint32_t)strtoul(end ? end : "", NULL, 10);
            do_bulk(lba, n);
            break;
        }

        case 'r': do_raw(arg); break;

        case 't': do_timing(arg); break;

        case 'A': do_async((uint32_t)strtoul(arg, NULL, 10)); break;

        case 'R':
            ata_bus_recover();
            printf("  bus forced idle, PIO machines restarted\n");
            show_status();
            break;

        case 's': show_status(); break;

        case 'n': do_usb_state(); break;
        case 'a': do_n8_open(); break;
        case 'o': do_n8_read(arg); break;
        case 'v': do_n8_memtest(arg); break;
        case 'y': do_n8_bench(arg); break;
        case 'E': do_push_info(); break;
        case 'W': do_push_run(); break;

        case 'P': do_psram(arg); break;
        case 'S': do_disc_stats(); break;
        case 'O': do_autoplay(arg); break;
        case 'Y': disc_acquire(); break;
        case 'G': do_game(arg); break;
        case 'C': player_console(arg); break;
        case 'L': do_catalog_info(arg); break;
        case 'J': do_game_load(arg); break;
        case 'M': do_audio(arg); break;
        case 'B': do_bgm(arg); break;
        case 'V': do_level(arg); break;
        case 'T': do_tone(arg); break;

        case 'g': diag_snapshot(); break;
        case 'f': diag_float_scan(); break;
        case 'w': diag_short_scan(); break;
        case 'm': diag_monitor(); break;

        case 'p': {
            uint32_t g = (uint32_t)strtoul(arg, NULL, 10);
            if (g > 47) { printf("  usage: p <gpio 0..47>\n"); break; }
            diag_blink(g, 10);
            eject_init();                  // it leaves the pad driving
            break;
        }

        default:
            printf("  ? unknown '%c' - press h for help\n", cmd);
        }
    }
}

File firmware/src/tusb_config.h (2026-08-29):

// tusb_config.h - TinyUSB host stack config for the EverDrive N8 Pro leg.
//
// CFG_TUSB_MCU (=OPT_MCU_RP2040, correct for RP2350 -- the same hcd serves both
// parts), CFG_TUSB_OS, CFG_TUSB_DEBUG and RP2040_USB_HOST_MODE all arrive from
// the SDK's tinyusb cmake. Do not redefine them here.
#ifndef _TUSB_CONFIG_H_
#define _TUSB_CONFIG_H_

#ifndef CFG_TUSB_MCU
#error "CFG_TUSB_MCU must come from the tinyusb_host cmake target"
#endif

#define CFG_TUH_ENABLED             1
#define CFG_TUD_ENABLED             0
#define CFG_TUH_MAX_SPEED           OPT_MODE_FULL_SPEED
#define BOARD_TUH_RHPORT            0

#define CFG_TUH_MEM_SECTION
#define CFG_TUH_MEM_ALIGN           __attribute__ ((aligned(4)))

#define CFG_TUH_HUB                 0   // one device, hard-wired
#define CFG_TUH_DEVICE_MAX          1
#define CFG_TUH_ENUMERATION_BUFSIZE 256

#define CFG_TUH_CDC                 1
#define CFG_TUH_HID                 0
#define CFG_TUH_MSC                 0
#define CFG_TUH_VENDOR              0

// The N8 Pro is a native CDC-ACM (STM32F401 OTG-FS); the vendor serial drivers
// only add VID/PID tables that can never match.
#define CFG_TUH_CDC_FTDI            0
#define CFG_TUH_CDC_CP210X          0
#define CFG_TUH_CDC_CH34X           0

// pyserial asserts DTR/RTS and sets 921600 8N1 on open. Doing it
// during enumeration avoids an app-level control transfer, which has no timeout.
#define CFG_TUH_CDC_LINE_CONTROL_ON_ENUM \
        (CDC_CONTROL_LINE_STATE_DTR | CDC_CONTROL_LINE_STATE_RTS)
#define CFG_TUH_CDC_LINE_CODING_ON_ENUM \
        { 921600, CDC_LINE_CODING_STOP_BITS_1, CDC_LINE_CODING_PARITY_NONE, 8 }

// EPSIZE is how many bytes the stream layer hands the hcd per request, not
// wMaxPacketSize; 512 cuts completion events ~8x versus the 64-byte default.
#define CFG_TUH_CDC_TX_EPSIZE       512
#define CFG_TUH_CDC_RX_EPSIZE       512
// Keep RX == TX: cdc_host.c sizes rx_ff_buf with the TX macro and the RX
// endpoint buffer with TX_EPSIZE, so a larger RX overruns a struct member.
#define CFG_TUH_CDC_TX_BUFSIZE      4096
#define CFG_TUH_CDC_RX_BUFSIZE      4096

#endif

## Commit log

2026-08-29 Initial commit - hardware and 3D models
    [bom.csv, cd_drive_bracket.stl, cd_eject_button.stl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]
2026-08-29 Add the firmware + example ROM
    [game.cfg, loops.csv]
2026-08-30 Add audio CD player ROM (why didn't I think of this earlier...)
    [audio.c]
2026-09-22 Fix picocom hang when drive doesn't answer
    [ata.c]
2026-09-22 Fix eject button responsiveness issues
    [ata.c, eject.c]
2026-09-23 Support for status LED
2026-10-04 Auto-launch the CD player when inserting an audio CD
2026-10-04 Fix non-looped audio tracks getting stuck before the last sample
2026-10-04 Prevent spinning up the drive when nothing is connected
    [main.c]
2026-10-15 Fix overly sensitive eject button
